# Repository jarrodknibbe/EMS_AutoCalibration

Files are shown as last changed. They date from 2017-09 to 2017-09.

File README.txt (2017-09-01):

We have been researching auto-calibration techniques for high-density Electric Muscle Stimulation.

In this repository, you will find the implementation details and source code of our initial prototype. 

To begin, please read the following paper:

Knibbe, J., Strohmeier, P., Boring, S., Hornbaek, K., Automatic Calibration of High Density Electric Muscle Stimulation, ACM IMWUT, September 2017.

To cut a long story short, EMS (Electric Muscle Stimulation) has two outstanding problems: (1) It is low resolution - we cannot target all muscles sufficiently to stimulate a full range of natural movement, and (2) calibration is hard. 

Typically, EMS uses pairs of large electrodes to target large muscle bodies. This enables us to control coarse movements, such as flexing the hand in and out. We believe that, in order to achieve higher resolution control (such as individual finger targeting), we need to use many smaller electrodes simultaneously. So instead of writing from 1 anode electrode to 1 cathode, we need to write from 8 anodes to 12 cathodes, or 14 anodes to 3 cathodes, or so on. This leads to another problem - calibration.

Even when only using pairs of large electrodes, calibration is a challenge. You have to find the optimal location for the electrodes and the optimal stimulation parameters. This involves placing, removing, re-placing electrodes and trial and error parameter exploration. This can easily take 5 minutes, and needs to be done per participant and per target movement. So, if you want to build an interactive system with only 4 movements, you are looking at 20 minutes of calibration prior to every use. 

If we now cover the arm in electrodes, as we intend to, the calibration process becomes increasingly complex - we now have to determine what combination of our electrodes to use for any movement. This explodes the possible unique combination of electrodes to 3^^n - 2^^n+1 + 2 (where n is the total number of electrodes). Clearly this is infeasible to test. 

So, we use EMG (electromyography) to read muscle activity between all electrodes and use this to inform our stimulation patterns with EMS. This means that the user manually performs a pose they would like to use, while we read EMG data, then we can use EMS to get them to re-perform that pose. 

In this repository, you will find the details of our prototype system for exploring this. The prototype includes a sports sleeve of 60 electrodes and the associated switching circuitry. We also include all of the control software.

If you use this, please cite:

Knibbe, J., Strohmeier, P., Boring, S., Hornbaek, K., Automatic Calibration of High Density Electric Muscle Stimulation, ACM IMWUT, September 2017.

Disclaimer:

Be careful. EMS can be dangerous or, at the very least, uncomfortable. You use the information here at your own risk.

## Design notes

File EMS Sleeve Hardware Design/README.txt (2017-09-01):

The hardware schematics included here are for an initial prototype to support our work. 

Each circuit board consists of:
- 3 shift registers SN74HC595N
- 24 solid state relays CPC1218Y

This enables switching control over 6 electrodes. As we have 60 electrodes in our prototype, we stacked 10 of the boards. The boards are designed to stack into a tower using alternating headers. 

Besides our custom circuit boards, we also use 1 off-the-shelf EMS unit (Med-Fit 1, though anything similar would do) and 2 EMG devices (Backyard Brains Muscle Spiker Shields). We remove the manual potentiometers from the EMS device and replace them with digital potentiometers (DS1803-050). This gives digital control over the amplitude, pulse width and frequency of the stimulation signal. 

All circuitry connects to an Arduino Mega. This cannot provide enough current to support the signal switching board, so we use a second Arduino Mega. This could also be provide by batteries, a power suplly, etc. Both of the Muscle Spiker Shields (for EMG) take their own Arduino Uno. 

There are undoubtedly optimisations and improvements that can be made. Current limitations or points for consideraion:

1. Our design did not focus on a small form factor, so ends up being quite large (as can be seen in the figures in the associated paper). 
2. We have reason to believe that our choice of relay (CPC1218Y) was also not sufficient for switching all possible signals out of our EMS device (the voltage can go above the limit of the relay). We never noticed any failure behaviour, but a CPC1215 may be more appropriate. I think, if I were to make the adjustments for a different relay, I would consider smaller surface mount relay options, to reduce the overall form factor. 
3. The EMG read process is too slow. The switching of the relays introduces noise to the EMG signal, requiring waiting between switching and reading. This means that our device can only read information for poses, not dynamic gestures. In the future, more EMG devices are needed to increase the speed of the reading cycle. 
4. The resolution of the Muscle Spiker Shields is too low. A higher-bit ADC is required to get the most out of the signal.

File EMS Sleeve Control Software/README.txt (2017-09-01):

This is the control circuitry for the sleeve. 

The code uses:
- scikit-learn
- numpy
- tkinter
- PIL
- matplotlib
- scipy
- serial

You may find that not all of these are actually necessary.

Start with 'gui.py' - this should guide you through the whole process. 

The code for the Arduino Mega is also included. This could be adapted so that different arduinos can be used, alongside more shift registers or multiplexers.

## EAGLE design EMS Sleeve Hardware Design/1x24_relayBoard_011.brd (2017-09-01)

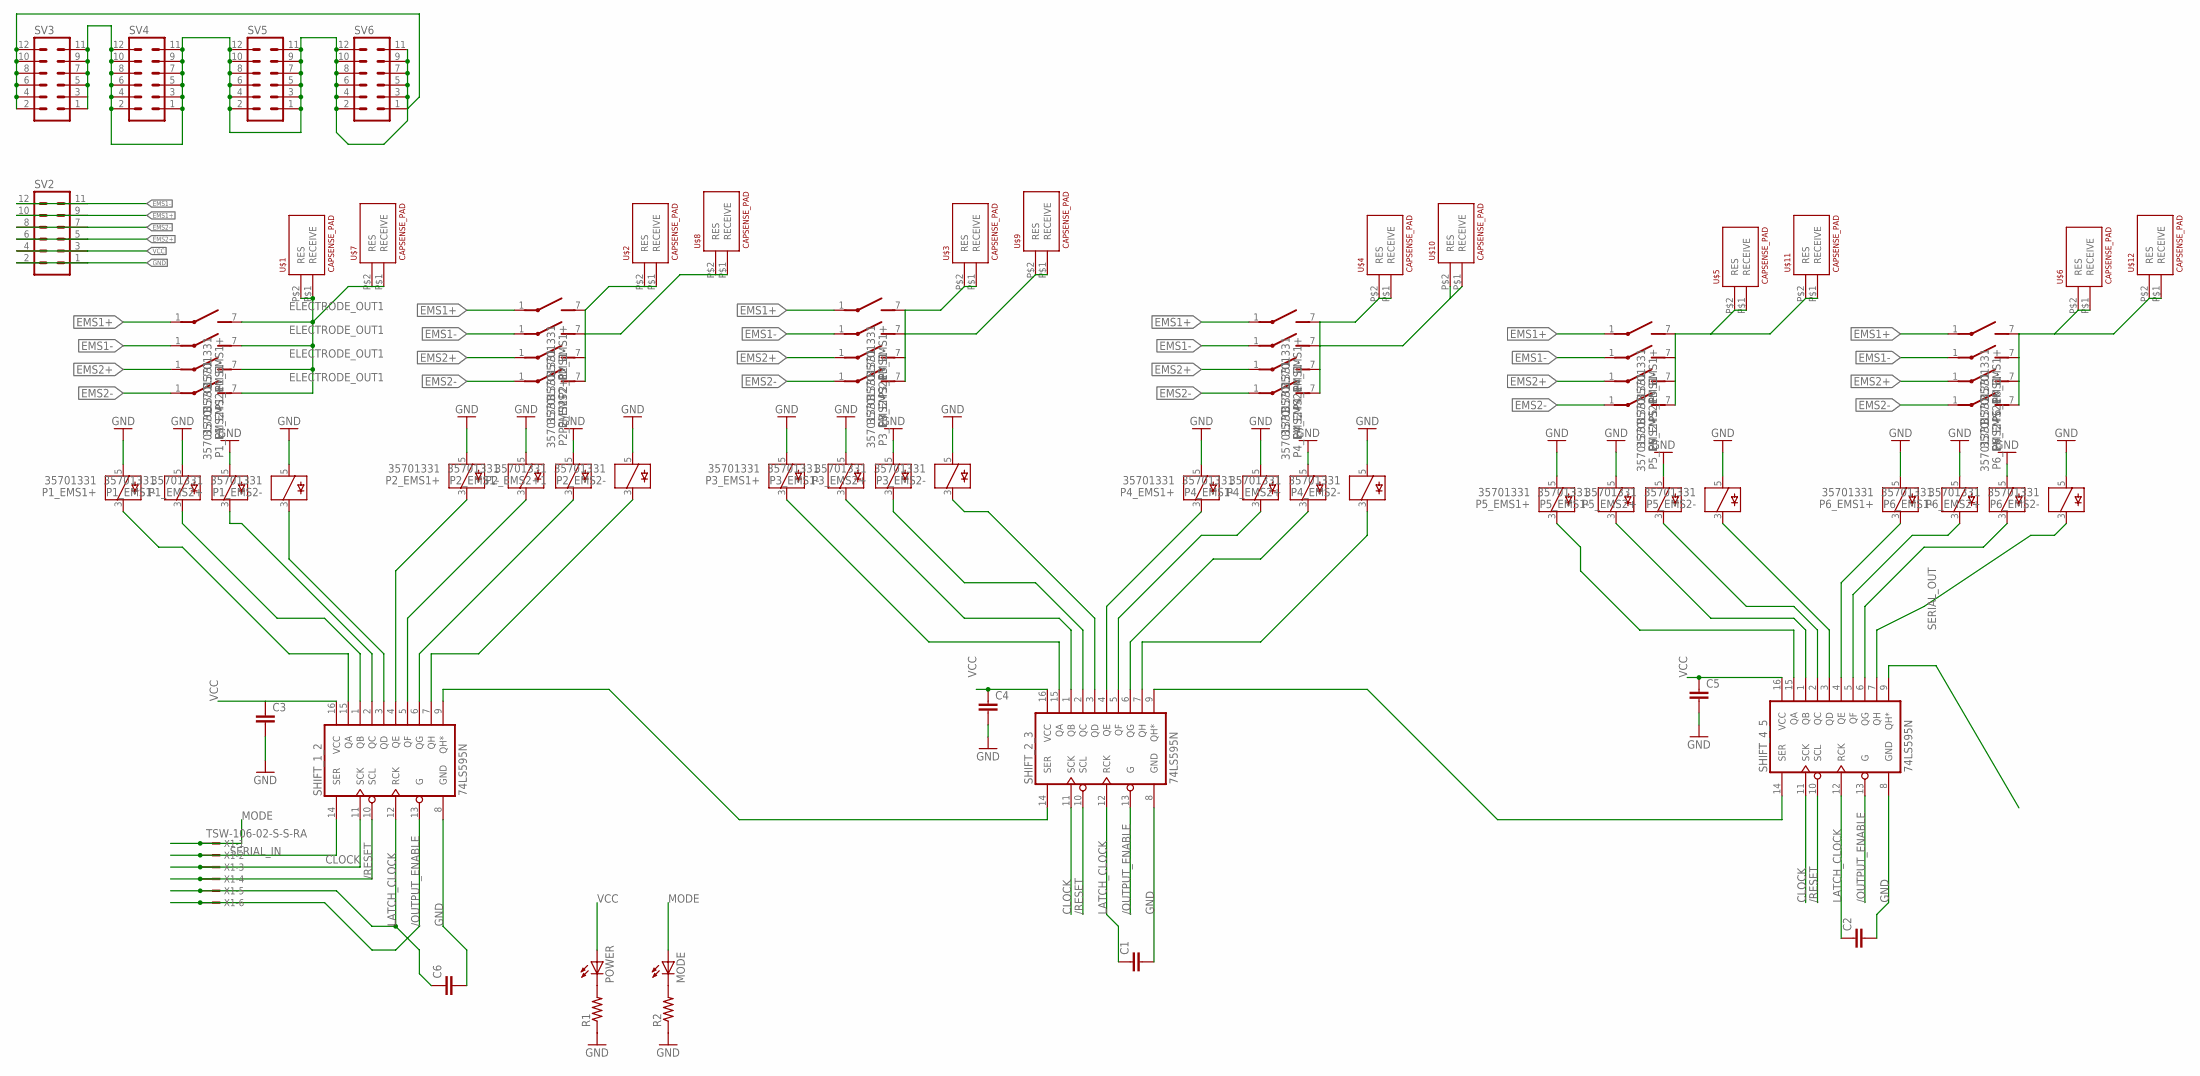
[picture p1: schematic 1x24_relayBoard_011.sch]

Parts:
C1, C2, C3, C4, C5, C6: C5/5; C5B5
MODE: LED_E; LED_1206
P1_EMS1+, P1_EMS1-, P1_EMS2+, P1_EMS2-, P2_EMS1+, P2_EMS1-, P2_EMS2+1, P2_EMS2-, P3_EMS1+, P3_EMS1-, P3_EMS2+, P3_EMS2-, P4_EMS1+, P4_EMS1-, P4_EMS2+, P4_EMS2-, P5_EMS1+, P5_EMS1-, P5_EMS2+, P5_EMS2-, P6_EMS1+, P6_EMS1-, P6_EMS2+, P6_EMS2-: 35701331; REED
POWER: LED_E; LED_1206
R1, R2: R-US_M1206; M1206
SHIFT_1_2, SHIFT_2_3, SHIFT_4_5: 74LS595N; DIL16
SV2, SV3, SV4, SV5, SV6: MA06-2
U$1, U$2, U$3, U$4, U$5, U$6, U$7, U$8, U$9, U$10, U$11, U$12: CAPSENSE_PAD
X1: TSW-106-02-S-S-RA

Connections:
/OUTPUT_ENABLE: SHIFT_1_2.13 (G), SHIFT_2_3.13 (G), SHIFT_4_5.13 (G), X1.6
/RESET: SHIFT_1_2.10 (SCL), SHIFT_2_3.10 (SCL), SHIFT_4_5.10 (SCL), X1.4
CLOCK: SHIFT_1_2.11 (SCK), SHIFT_2_3.11 (SCK), SHIFT_4_5.11 (SCK), X1.3
ELECTRODE_OUT1: P1_EMS1+.7 (S), P1_EMS1-.7 (S), P1_EMS2+.7 (S), P1_EMS2-.7 (S), U$1.P$1 (RECEIVE), U$1.P$2 (RES), U$7.P$1 (RECEIVE), U$7.P$2 (RES)
EMS1+: P1_EMS1+.1, P2_EMS1+.1, P3_EMS1+.1, P4_EMS1+.1, P5_EMS1+.1, P6_EMS1+.1, SV2.9, SV2.10
EMS1-: P1_EMS1-.1, P2_EMS1-.1, P3_EMS1-.1, P4_EMS1-.1, P5_EMS1-.1, P6_EMS1-.1, SV2.11, SV2.12
EMS2+: P1_EMS2+.1, P2_EMS2+1.1, P3_EMS2+.1, P4_EMS2+.1, P5_EMS2+.1, P6_EMS2+.1, SV2.5, SV2.6
EMS2-: P1_EMS2-.1, P2_EMS2-.1, P3_EMS2-.1, P4_EMS2-.1, P5_EMS2-.1, P6_EMS2-.1, SV2.7, SV2.8
GND: C1.2, C2.2, C3.2, C4.2, C5.2, C6.2, P1_EMS1+.5, P1_EMS1-.5, P1_EMS2+.5, P1_EMS2-.5, P2_EMS1+.5, P2_EMS1-.5, P2_EMS2+1.5, P2_EMS2-.5, P3_EMS1+.5, P3_EMS1-.5, P3_EMS2+.5, P3_EMS2-.5, P4_EMS1+.5, P4_EMS1-.5, P4_EMS2+.5, P4_EMS2-.5, P5_EMS1+.5, P5_EMS1-.5, P5_EMS2+.5, P5_EMS2-.5, P6_EMS1+.5, P6_EMS1-.5, P6_EMS2+.5, P6_EMS2-.5, R1.1, R2.1, SHIFT_1_2.8 (GND), SHIFT_2_3.8 (GND), SHIFT_4_5.8 (GND), SV2.1, SV2.2, SV3.1, SV3.2, SV3.3, SV3.4, SV3.5, SV3.6, SV3.7, SV3.8, SV3.9, SV3.10, SV3.11, SV3.12, SV4.1, SV4.2, SV4.3, SV4.4, SV4.5, SV4.6, SV4.7, SV4.8, SV4.9, SV4.10, SV4.11, SV4.12, SV5.1, SV5.2, SV5.3, SV5.4, SV5.5, SV5.6, SV5.7, SV5.8, SV5.9, SV5.10, SV5.11, SV5.12, SV6.1, SV6.2, SV6.3, SV6.4, SV6.5, SV6.6, SV6.7, SV6.8, SV6.9, SV6.10, SV6.11, SV6.12
LATCH_CLOCK: C1.1, C2.1, C6.1, SHIFT_1_2.12 (RCK), SHIFT_2_3.12 (RCK), SHIFT_4_5.12 (RCK), X1.5
MODE: MODE.A, X1.1
unnamed: P3_EMS1+.3, SHIFT_2_3.15 (QA)
unnamed: P1_EMS1+.3, SHIFT_1_2.15 (QA)
unnamed: P1_EMS1-.3, SHIFT_1_2.1 (QB)
unnamed: P1_EMS2+.3, SHIFT_1_2.2 (QC)
unnamed: P1_EMS2-.3, SHIFT_1_2.3 (QD)
unnamed: P2_EMS1+.3, SHIFT_1_2.4 (QE)
unnamed: P2_EMS1-.3, SHIFT_1_2.5 (QF)
unnamed: P2_EMS2+1.3, SHIFT_1_2.6 (QG)
unnamed: P2_EMS2-.3, SHIFT_1_2.7 (QH)
unnamed: P3_EMS1-.3, SHIFT_2_3.1 (QB)
unnamed: P3_EMS2+.3, SHIFT_2_3.2 (QC)
unnamed: P3_EMS2-.3, SHIFT_2_3.3 (QD)
unnamed: P4_EMS1+.3, SHIFT_2_3.4 (QE)
unnamed: P4_EMS1-.3, SHIFT_2_3.5 (QF)
unnamed: P4_EMS2+.3, SHIFT_2_3.6 (QG)
unnamed: P4_EMS2-.3, SHIFT_2_3.7 (QH)
unnamed: P5_EMS1+.3, SHIFT_4_5.15 (QA)
unnamed: P5_EMS1-.3, SHIFT_4_5.1 (QB)
unnamed: P5_EMS2+.3, SHIFT_4_5.2 (QC)
unnamed: P5_EMS2-.3, SHIFT_4_5.3 (QD)
unnamed: P6_EMS1+.3, SHIFT_4_5.4 (QE)
unnamed: P6_EMS1-.3, SHIFT_4_5.5 (QF)
unnamed: P6_EMS2+.3, SHIFT_4_5.6 (QG)
unnamed: P6_EMS2-.3, SHIFT_4_5.7 (QH)
unnamed: P2_EMS1+.7 (S), P2_EMS1-.7 (S), P2_EMS2+1.7 (S), P2_EMS2-.7 (S), U$2.P$1 (RECEIVE), U$2.P$2 (RES), U$8.P$1 (RECEIVE), U$8.P$2 (RES)
unnamed: P3_EMS1+.7 (S), P3_EMS1-.7 (S), P3_EMS2+.7 (S), P3_EMS2-.7 (S), U$3.P$1 (RECEIVE), U$3.P$2 (RES), U$9.P$1 (RECEIVE), U$9.P$2 (RES)
unnamed: P4_EMS1+.7 (S), P4_EMS1-.7 (S), P4_EMS2+.7 (S), P4_EMS2-.7 (S), U$4.P$1 (RECEIVE), U$4.P$2 (RES), U$10.P$1 (RECEIVE), U$10.P$2 (RES)
unnamed: P5_EMS1+.7 (S), P5_EMS1-.7 (S), P5_EMS2+.7 (S), P5_EMS2-.7 (S), U$5.P$1 (RECEIVE), U$5.P$2 (RES), U$11.P$1 (RECEIVE), U$11.P$2 (RES)
unnamed: P6_EMS1+.7 (S), P6_EMS1-.7 (S), P6_EMS2+.7 (S), P6_EMS2-.7 (S), U$6.P$1 (RECEIVE), U$6.P$2 (RES), U$12.P$1 (RECEIVE), U$12.P$2 (RES)
unnamed: SHIFT_1_2.9 (QH*), SHIFT_2_3.14 (SER)
unnamed: SHIFT_2_3.9 (QH*), SHIFT_4_5.14 (SER)
unnamed: POWER.C, R1.2
unnamed: MODE.C, R2.2
SERIAL_IN: SHIFT_1_2.14 (SER), X1.2
SERIAL_OUT: SHIFT_4_5.9 (QH*)
VCC: C3.1, C4.1, C5.1, POWER.A, SHIFT_1_2.16 (VCC), SHIFT_2_3.16 (VCC), SHIFT_4_5.16 (VCC), SV2.3, SV2.4

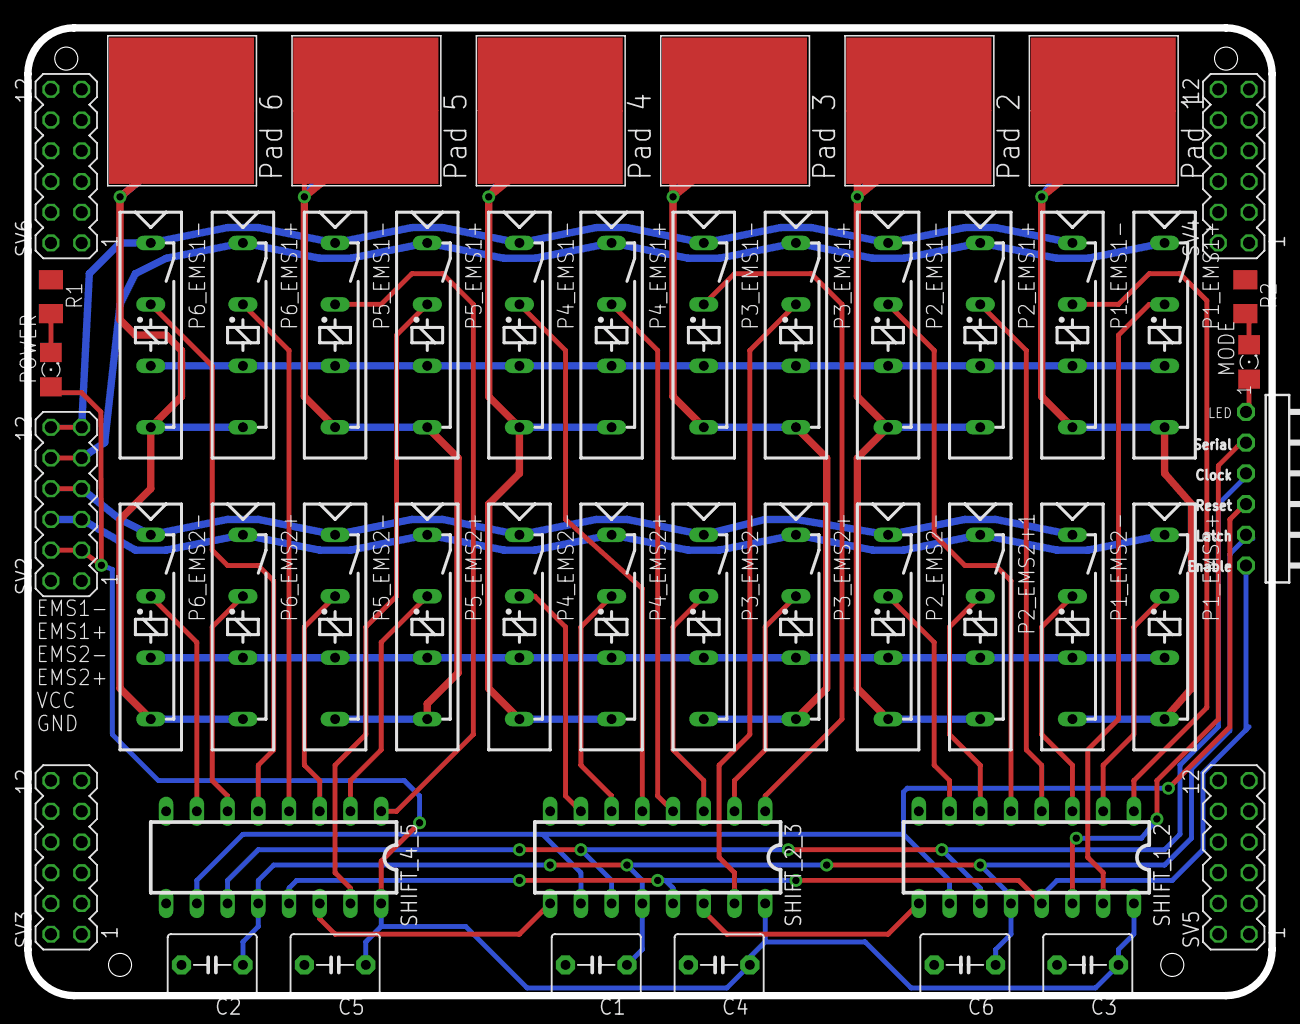
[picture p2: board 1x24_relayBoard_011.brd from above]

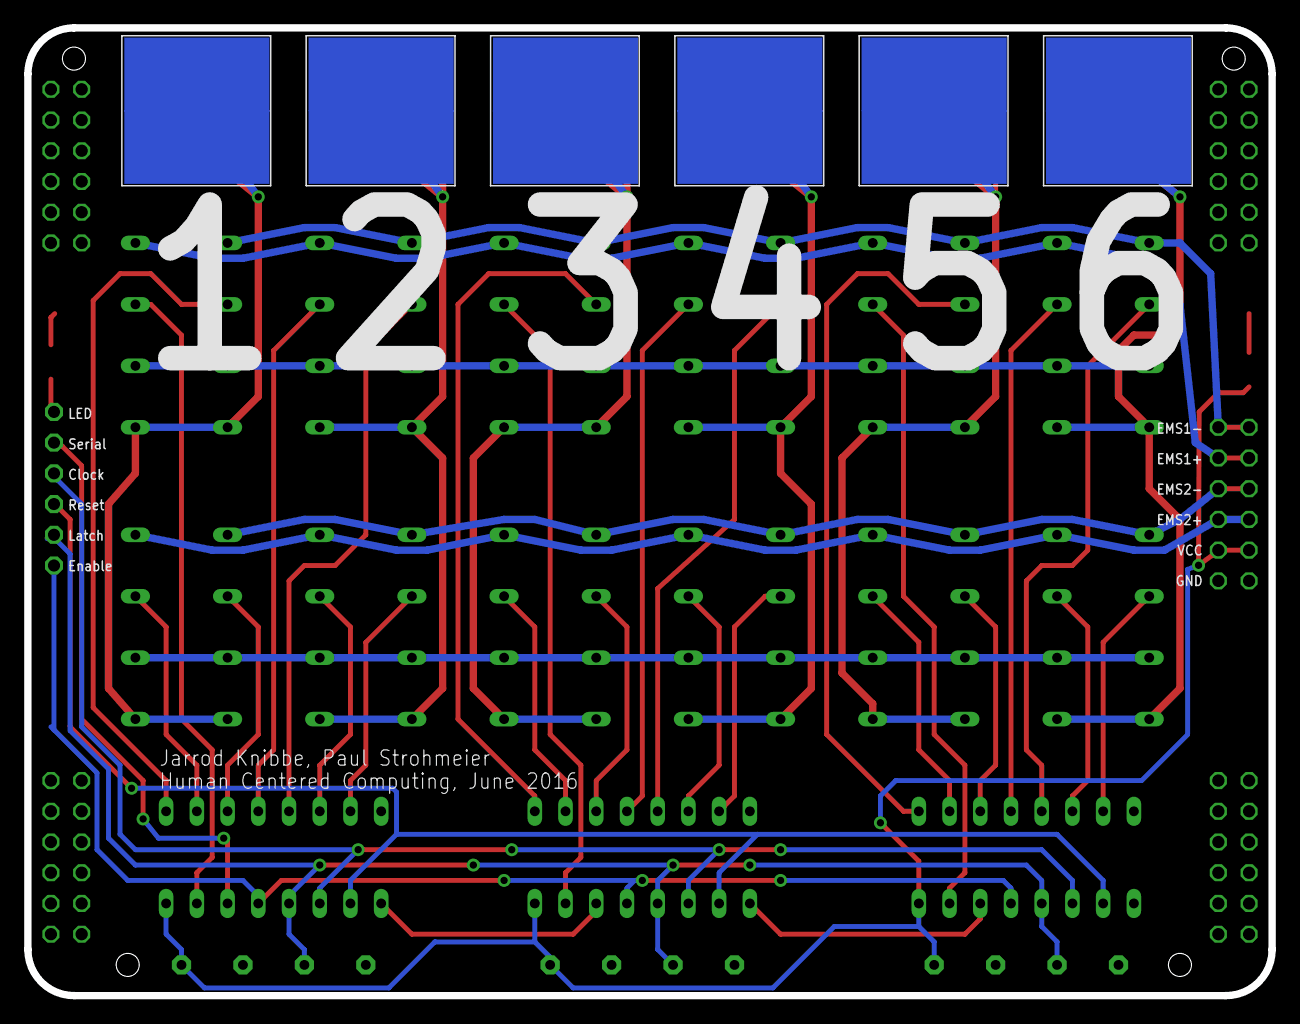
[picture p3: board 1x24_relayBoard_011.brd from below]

Board: 2 copper layers, 102.9 x 80.0 mm, 55 parts (6 on the bottom side), 46 nets.

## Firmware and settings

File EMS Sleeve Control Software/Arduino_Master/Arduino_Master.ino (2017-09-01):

//Controlling Mux through library:
//https://github.com/federico-galli/Arduino-dual-i2c-potentiometer-DS1803
//Also needs wire
#include <DS1803.h>
#include <Wire.h>

//2 operating states - EMG, (EMG collect), EMS
boolean gather_EMG = false;
boolean gather_EMG_collect = false;
boolean gather_EMG_specific = false;
boolean stim_EMS = false;

//-------------- EMG Variables
//switch power to EMGs
int power_EMG_switch = A15;

//EMG relay switches
int signal_EMG_1_pos_switch = 2;
int signal_EMG_1_neg_switch = 3;
int signal_EMG_2_pos_switch = 4;
int signal_EMG_2_neg_switch = 5;

//Read EMG input from
int signals_EMG[] = {A1, A2}; 

//Data array for storing EMG values
int readings_EMG[2][200];
int readings_EMG_count = 0;

//-------------- EMS Variables
//Switch power to EMS
int power_EMS_switch = 6;
int signal_EMS_1_pos_switch = 7;
int signal_EMS_1_neg_switch = 8;
int signal_EMS_2_pos_switch = 9;
int signal_EMS_2_neg_switch = 10;

//DigiPot pot_width(pulse width, frequency), DigiPot pot_chans(Chan 1, +/-),(Chan 2, +/-)
DS1803 pot_width(0x2C);
//DS1803 pot_width_2(0x2E);
DS1803 pot_chans(0x28);

//Active channel tracker
//Ensuring opposite channel is active before running EMG
int active_channels[] = {0,0,0,0};

//4 inputs per sleeve row
//Electrode data class
struct electrode{
	int chan;
};

//Sleeve row data class
struct electrode_row{
	electrode electrodes[6];
	//latch, clock, data, outputEnable
	int shift_pins[4];
};

//10 rows of electrodes
electrode_row sleeve[10];

//Circuit Debug Variables
int EMS_LED = A14;
int EMG_LED = A13;

//Debug print buffer
char buffers[16];

void setup(){
	Serial.begin(38400);

	int curr_digi_pin_count = 11;

	//Sleeve Creation
	for (int i = 0; i < 10; i++) {
		//Set all electrodes off to start with
		for (int j = 0; j < 6; j++) {
			sleeve[i].electrodes[j].chan = -1;
		}

		for (int j = 0; j < 4; j++) {
			sleeve[i].shift_pins[j] = curr_digi_pin_count;

			curr_digi_pin_count += 1;
			pinMode(sleeve[i].shift_pins[j], OUTPUT);

			if (curr_digi_pin_count == 19) curr_digi_pin_count += 3;
		}
	}
	write_output_enable(true);

	//EMG Setup
	pinMode(power_EMG_switch, OUTPUT);

	pinMode(signal_EMG_1_pos_switch, OUTPUT);
	pinMode(signal_EMG_1_neg_switch, OUTPUT);
	pinMode(signal_EMG_2_pos_switch, OUTPUT);
	pinMode(signal_EMG_2_neg_switch, OUTPUT);
	for (int i = 0; i < 2; i++) {
		pinMode(signals_EMG[i], INPUT);
	}

	//EMS Setup
	pinMode(signal_EMS_1_pos_switch, OUTPUT);
	pinMode(signal_EMS_1_neg_switch, OUTPUT);
	pinMode(signal_EMS_2_pos_switch, OUTPUT);
	pinMode(signal_EMS_2_neg_switch, OUTPUT);
	pinMode(power_EMS_switch, OUTPUT);
	pot_chans.setPot(0, 0);
	pot_chans.setPot(0, 1);
	pot_width.setPot(0,0);
	pot_width.setPot(0,1);
	//pot_width_2.setPot(0,0);
	//pot_width_2.setPot(0,1);

	//Circuit Debug Setup
	pinMode(EMS_LED, OUTPUT);
	pinMode(EMG_LED, OUTPUT);
}

void loop() {
	//if running EMG, then wait for finish, else wait for new input
	if (gather_EMG_collect == true) {
//		unsigned long StartTime = micros();
		run_EMG_read_multi();
//		unsigned long CurrentTime = micros();
//		unsigned long ElapsedTime = CurrentTime - StartTime;
//                Serial.println(ElapsedTime);
	}
	else {
		readInputLine();
		//update_sleeve_row_all();
	}
}

//Read analog for all EMG signals up to read_row_max_EMG
void run_EMG_read_single(){
 	while (readings_EMG_count < 120){
		readings_EMG[0][readings_EMG_count] = analogRead(signals_EMG[0]);
		readings_EMG_count++;
		//delay(2);
  	}
	report_EMG_to_python_single();
	gather_EMG_collect = false;
	clear_signal_selection();
	readings_EMG_count = 0;
}

//Write completed columns to serial, for python
void report_EMG_to_python_single() {
	Serial.print("EMG ");
	for (int i = 100; i < 120; i++)
	{
		Serial.print(readings_EMG[0][i]);
		Serial.print(" ");
	}
	Serial.println();
}

//Read analog for all EMG signals up to read_row_max_EMG
void run_EMG_read_multi(){
//        unsigned long StartTime = micros();
 	while (readings_EMG_count < 50){
		readings_EMG[0][readings_EMG_count] = analogRead(signals_EMG[0]);
		readings_EMG[1][readings_EMG_count] = analogRead(signals_EMG[1]);
		readings_EMG_count++;
		delay(1);
  	}
//        unsigned long CurrentTime = micros();
//        unsigned long ElapsedTime = CurrentTime - StartTime;
//        Serial.println(ElapsedTime);
	report_EMG_to_python_multi();
	gather_EMG_collect = false;
//	clear_signal_selection();
	readings_EMG_count = 0;
}

//Write completed columns to serial, for python
void report_EMG_to_python_multi() {
	for (int j = 0; j < 2; j++){
		String toPrint;
		//toPrint = "EMG ";
		Serial.print("EMG ");
                Serial.print(j);
                Serial.print(" ");
		for (int i = 20; i < 50; i++)
		{
//			toPrint += readings_EMG[j][i];
//			toPrint += " ";
			Serial.print(readings_EMG[j][i]);
			Serial.print(" ");
		}
		Serial.println();
	}
}

//Read control signals from serial
//Signals:
//3 = Off/Neutral Mode
//4 = read EMG Mode (specific electrodes)
//5 = run EMS Mode (random walk)
//returns true (if read), false (if unavailable)
void readInputLine(){
	if (Serial.available()) {
		int commandValue = Serial.parseInt();
		char labelValue = Serial.read();

		//Serial.print(commandValue);
		//Serial.println(labelValue);

		//Deal with main flag commands and enable/disable switches
		if (commandValue < 7 && labelValue == 'c') {
			reset_flags();
			switch (commandValue) {
				case 1 :
					break;
				case 2:
					break;
				case 3:
					clear_signal_selection();
					break;
				case 4: 
					gather_EMG = true;
					clear_signal_selection();
					digitalWrite(power_EMG_switch, HIGH);
					digitalWrite(signal_EMG_1_pos_switch, HIGH);
					digitalWrite(signal_EMG_1_neg_switch, HIGH);
					digitalWrite(signal_EMG_2_pos_switch, HIGH);
					digitalWrite(signal_EMG_2_neg_switch, HIGH);
					digitalWrite(EMG_LED, HIGH);
					break;
				case 5: 
					clear_signal_selection();
					stim_EMS = true;
					pot_chans.setPot(0, 0);
					pot_chans.setPot(0, 1);
					pot_width.setPot(0,0);
					pot_width.setPot(0,1);
					//pot_width_2.setPot(0,0);
					//pot_width_2.setPot(0,1);
					digitalWrite(power_EMS_switch, HIGH);
					digitalWrite(signal_EMS_1_pos_switch, HIGH);
					digitalWrite(signal_EMS_1_neg_switch, HIGH);
					digitalWrite(signal_EMS_2_pos_switch, HIGH);
					digitalWrite(signal_EMS_2_neg_switch, HIGH);
					digitalWrite(EMS_LED, HIGH);
					break;
				default:
					break;   
			}
		}

		//Get values to configure EMS or control sleeve
		//Format (n = int variable)
		//-----'nr nt ni' = row, col, channel
		//-----'np' = pulse width, 'nz' = frequency
		//-----'na' = chan 1 amplitude, 'ng' = chan 2 amplitude
		if (gather_EMG || stim_EMS) {

			switch (labelValue) {
				case 'r':
                {
					int colValue = Serial.parseInt();
					char colLabel = Serial.read();

					int chanValue = Serial.parseInt();
					char chanLabel = Serial.read();

					//Set electrode channel value
					if (labelValue == 'r' && colLabel == 't' && chanLabel == 'i') {
						if (chanValue < 0){
							active_channels[sleeve[commandValue].electrodes[colValue].chan] -= 1;
						}
                                                
						sleeve[commandValue].electrodes[colValue].chan = chanValue;

						if (chanValue >=0){
							active_channels[chanValue] += 1;
						}
					}

					//Update the whole sleeve row
					update_sleeve_row(commandValue);

					if (chanValue >= 0 && gather_EMG && check_opposite_channel(chanValue)) gather_EMG_collect = true;

					break;
				}
				case 'p' :
				{
					int freqValue = Serial.parseInt();
					int freqLabel = Serial.read();

					if (freqLabel == 'z') {
						pot_width.setPot(int(commandValue), 0);
						pot_width.setPot(int(freqValue), 1);
						//pot_width_2.setPot(int(commandValue), 0);
						//pot_width_2.setPot(int(freqValue), 1);
					}
					break;
				}
				case 'a' :
				{
					int chan2Value = Serial.parseInt();
					int chan2Label = Serial.read();

					if (chan2Label == 'g') {
						pot_chans.setPot(commandValue, 0);
						pot_chans.setPot(chan2Value, 1);
					}
					break;
				}
				case 'f' :
					set_whole_sleeve_row(commandValue, false);
					break;
				case 'u' :
					set_whole_sleeve_row(commandValue, true);
					break;
				default:
					break;
			}
		}
	}
}

void update_sleeve_row_all(){
  for (int uarow = 0; uarow < 10; uarow++){
    //Serial.print("Updating row ");  
    //Serial.println(uarow);  
    if (check_row_active(uarow)) update_sleeve_row(uarow);
  }
}

boolean check_row_active(int curr_row){
  for (int i = 0; i < 6; i++) {
    if (sleeve[curr_row].electrodes[i].chan >= 0){
      return true;
    }
  }
  return false;
}

//Not check opposite, check all
boolean check_opposite_channel(int chan){
	bool all_active = true;
	for (int i = 0; i < 4; i++) {
		if (active_channels[i] == 0) all_active = false;
	}
	return all_active;
  //int target_chan = -1;
  //target_chan = (chan % 2 == 0 ? chan + 1 : chan - 1);
  //return (active_channels[target_chan] > 0);
}

void set_whole_sleeve_row(int row, bool on_off){
	byte vals[3];

	for (int i = 0; i < 3; i++) vals[i] = 0;

	for (int i = 0; i < 6; i++) {
		if (on_off) bitSet(vals[int(i/2)], on_off + ((i%2)*4));
	}

	digitalWrite(sleeve[row].shift_pins[0], LOW);
	for (int i = 2; i >= 0; i--) {
		//Serial.println(vals[i]);
		shiftOut(sleeve[row].shift_pins[2], sleeve[row].shift_pins[1], MSBFIRST, vals[i]);
	}
	//Serial.println("*************");
	digitalWrite(sleeve[row].shift_pins[0], HIGH);
	digitalWrite(sleeve[row].shift_pins[3], LOW);
}

void update_sleeve_row(int row){
	byte vals[3];

	for (int i = 0; i < 3; i++) vals[i] = 0;

	//loop through all electrodes and set byte values
	for (int i = 0; i < 6; i++){
		if (sleeve[row].electrodes[i].chan >= 0) {
			bitSet(vals[int(i/2)], sleeve[row].electrodes[i].chan + ((i%2)*4));
		}
	}

	digitalWrite(sleeve[row].shift_pins[0], LOW);
	for (int i = 2; i >= 0; i--) {
		//Serial.println(vals[i]);
		shiftOut(sleeve[row].shift_pins[2], sleeve[row].shift_pins[1], MSBFIRST, vals[i]);
	}
	//Serial.println("*************");
	digitalWrite(sleeve[row].shift_pins[0], HIGH);
	digitalWrite(sleeve[row].shift_pins[3], LOW);
}

void clear_signal_selection(){
	for (int row = 0; row < 10; row++) {
		if (check_row_active(row)){
			for (int col = 0; col < 6; col++) {
    			sleeve[row].electrodes[col].chan = -1;
    		}
    		update_sleeve_row(row);
        }
	}
	for (int chans = 0; chans < 4; chans++){
		active_channels[chans] = 0;
	}
}

void write_output_enable(boolean enable){
  for (int row = 0; row < 10; row++){
    for (int col = 0; col < 6; col++){
      digitalWrite(sleeve[row].shift_pins[3], enable);
    }
  }
}

void reset_flags(){
	gather_EMG = false;
    gather_EMG_collect = false;
	digitalWrite(power_EMG_switch, LOW);
	digitalWrite(signal_EMG_1_pos_switch, LOW);
	digitalWrite(signal_EMG_1_neg_switch, LOW);
	digitalWrite(signal_EMG_2_pos_switch, LOW);
	digitalWrite(signal_EMG_2_neg_switch, LOW);
	stim_EMS = false;
	pot_chans.setPot(0, 0);
	pot_chans.setPot(0, 1);
	pot_width.setPot(0,0);
	pot_width.setPot(0,1);
	//pot_width_2.setPot(0,0);
	//pot_width_2.setPot(0,1);
	digitalWrite(power_EMS_switch, LOW);
	digitalWrite(signal_EMS_1_pos_switch, LOW);
	digitalWrite(signal_EMS_1_neg_switch, LOW);
	digitalWrite(signal_EMS_2_pos_switch, LOW);
	digitalWrite(signal_EMS_2_neg_switch, LOW);
	digitalWrite(EMG_LED, LOW);
	digitalWrite(EMS_LED, LOW);
}

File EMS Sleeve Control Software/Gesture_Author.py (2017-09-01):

#----------------------
#Electrode visualisation class
#Draws representations of sleeve array and controls
#Enables control of parameters
#----------------------

#Import libraries
import numpy as np
import cv2
import serial
import time
import datetime
import pytz
import random
import matplotlib
matplotlib.use("TkAgg")
from matplotlib import pyplot as plt
from matplotlib.backends.backend_tkagg import FigureCanvasTkAgg, NavigationToolbar2TkAgg
import Tkinter as tkinter
from PIL import Image
from collections import deque
import os
import io
import subprocess
import threading
import math

# Import neighbor/support classes
from Gesture_Sequencer import *
from Sleeve_Link import send_command, set_controller_amplitude, set_controller_freq_pwm, set_sleeve_electrodes, set_all_sleeve_electrodes, reset_connection
from File_Link import initialise_file, write_single_line_file, write_sleeve_status_to_file, find_number_of_poses, write_electrodes_to_file, load_pose_list

#True if running from EMG data
calibrated_pose = False

#Track number of active electrodes, only turn on EMS if > 2
num_active_electrodes = 0

#Initialise stimulation parameters, electrode array representations, etc.
EMG_ch1 = 0
EMG_ch2 = 0
EMG_pwm = 0
EMG_freq = 0
data = np.zeros(shape=(0,0))

#Ramps up to a predefined amplitude, with 0.03s step
#Input - start amplitude, target/end amplitude
def ramp_to_amplitude(start_amp, end_amp):
	global EMG_ch2, EMG_ch1, stim_Ratio

	EMG_ch2 = 0
	EMG_ch1 = 0
	set_controller_amplitude()

	for i in range(start_amp,end_amp):
		EMG_ch2 += 1
		EMG_ch1 = int(EMG_ch2 * stim_Ratio)
		set_controller_amplitude()

		time.sleep(0.03)

	print "Ramp Done"

#Function called when sleeve array clicked
def control_stim_electrode(event):
	electrode_selected = [int(event.x/40), int(event.y/30)]
	global electrodes, data
	electrodes.itemconfig("rec" + str(electrode_selected[0]) + "_" + str(electrode_selected[1]), fill="blue")

	#If left mouse click, increase channel selection
	if event.num == 1:

		pre_value = 0
		data[electrode_selected[1]][electrode_selected[0]] += 1
		data[electrode_selected[1]][electrode_selected[0]] %= 5
		
	#If right mouse click, turn off electrode
	if event.num != 1:
		print "Right click - disengage"
		pre_value = data[electrode_selected[1]][electrode_selected[0]]
		data[electrode_selected[1]][electrode_selected[0]] = 0

	load_balancing(data[electrode_selected[1]][electrode_selected[0]], False, False, pre_value)
	global EMG_ch1, EMG_ch2
	set_controller_amplitude(EMG_ch1, EMG_ch2)
	set_sleeve_electrodes(electrode_selected[0], electrode_selected[1], data[electrode_selected[1]][electrode_selected[0]])

	update_sleeve_drawing()
	update_controls_drawing()

#triggered when stim control bars clicked
def control_stim_signal(event):
	click_location = 4
	click_value = event.x
	if event.x > 0 and event.x < 250:
		click_location = int(event.y/60)

		#0 = pwm, 1 = freq, 2 = ch1, 3 = ch2
		if click_location == 0:
			global EMG_pwm
			EMG_pwm = int(click_value)
			set_controller_freq_pwm(EMG_pwm, EMG_freq)
		elif click_location == 1:
			global EMG_freq
			EMG_freq = int(click_value)
			set_controller_freq_pwm(EMG_pwm, EMG_freq)
		elif click_location == 2:
			global EMG_ch1, EMG_ch2, stim_Ratio, calibrated_pose
			EMG_ch1 = int(click_value)
			load_balancing(0, True, False)
			set_controller_amplitude(EMG_ch1, EMG_ch2)
		elif click_location == 3:
			global EMG_ch2, EMG_ch1, stim_Ratio, calibrated_pose
			EMG_ch2 = int(click_value)
			load_balancing(0, True, True)
			set_controller_amplitude(EMG_ch1, EMG_ch2)

		time.sleep(0.1)
		send_sock_command(participant_ID_, 1, curr_gesture)
		global participant_ID_, pose_number
		write_sleeve_status_to_file(participant_ID_, pose_number, True, "machine", electrodes, data, curr_gesture, EMG_ch1, EMG_ch2, EMG_pwm, EMG_freq)

	update_controls_drawing()

#handle keyboard shortcuts for signal control
def keyboard_control_stim(event):
	print "Keypress ", event.char
	chan2_change = False

	global EMG_ch1, EMG_ch2, stim_Ratio, calibrated_pose, EMG_freq, EMG_pwm, stop_EMS_ramp, playLoop, curr_gesture
	if event.char == 'm':
		EMG_ch2 += 1
		chan2_change = True
	elif event.char == 'n':
		EMG_ch2 -= 1
		chan2_change = True
		if EMG_ch2 <= 0:
			EMG_ch2 = 0
	elif event.char == 'c':
		EMG_ch1 -= 1
		if EMG_ch1 <= 0:
			EMG_ch1 = 0
	elif event.char == 'v':
		EMG_ch1 += 1
	elif event.char == ' ':
		EMG_ch2 = 0
		EMG_ch1 = 0
		stop_EMS_ramp = True
		playLoop = False
	elif event.char == 'g':
		EMG_freq += 1
	elif event.char == 'f':
		EMG_freq -= 1
	elif event.char == 'h':
		EMG_pwm -= 1
	elif event.char == 'j':
		EMG_pwm += 1
	else:
		global data, key_poses
		for targets in key_poses:
			if event.char == targets[0]:
				data = np.copy(targets[1])
				EMG_ch1 = targets[2]
				EMG_ch2 = targets[3]
				EMG_freq = targets[4]
				EMG_pwm = targets[5]

				#Update drawings based on input
				update_sleeve_drawing()
				set_all_sleeve_electrodes()
				update_sleeve_drawing()

	#Ensure safe load balance
	#If multiple electrodes are removed, make sure amplitude is decreased
	load_balancing(0, True, chan2_change)

	#Trigger optitrack if either channel % 5 equals 0
	#Random(ish) step, change to increase/decrease 
	if EMG_ch2%5 == 0 or EMG_ch1%5 == 0:
		send_sock_command(participant_ID_, 1, curr_gesture)
	
	#set amplitudes and frequences, update graphics
	set_controller_amplitude(EMG_ch1, EMG_ch2)
	set_controller_freq_pwm(EMG_pwm, EMG_freq)
	update_controls_drawing()

#Re-draw sleeve graphic
def update_sleeve_drawing():
	global electrodes, num_electrode_rows, num_electrode_cols
	color_fill = ["white", "blue", "green", "red", "purple"]
	for x in range(0, num_electrode_cols):
		for y in range(0, num_electrode_rows):
				electrodes.itemconfig("rec" + str(x) + "_" + str(y), fill=color_fill[int(data[y][x])])

#redraw controls graphic
def update_controls_drawing():
	global controls, EMG_ch1, EMG_ch2, EMG_freq, EMG_pwm
	controls.coords("line0", (EMG_pwm, 0, EMG_pwm, 60))
	controls.coords("line1", (EMG_freq, 60, EMG_freq, 120))
	controls.coords("line2", (EMG_ch1, 120, EMG_ch1, 180))
	controls.coords("line3", (EMG_ch2, 180, EMG_ch2, 240))

#Balance loads, to maintain channel 1 and channel 2 ratios
def load_balancing(channel_change, amp_increase=False, ch2_increase=False, pre_channel=0):
	global stim_Ratio, EMG_ch2, EMG_ch1, calibrated_pose
	num_per_ch2 = len(zip(*np.where(data == 3)))
	num_per_ch1 = len(zip(*np.where(data == 1)))

	if not amp_increase:
		EMG_ch2 -= 20
		if EMG_ch2 <= 0:
			EMG_ch2 = 10

	if calibrated_pose and num_per_ch2 > 0:
		stim_per_e2 = (EMG_ch2 / (num_per_ch2))
		EMG_ch1 = int(stim_per_e2 * stim_Ratio) * num_per_ch1
	elif not calibrated_pose and not amp_increase:
		EMG_ch1 -= 20
		if EMG_ch1 <= 0:
			EMG_ch1 = 10
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

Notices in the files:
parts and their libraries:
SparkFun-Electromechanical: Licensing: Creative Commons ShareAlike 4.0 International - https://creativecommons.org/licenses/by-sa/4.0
